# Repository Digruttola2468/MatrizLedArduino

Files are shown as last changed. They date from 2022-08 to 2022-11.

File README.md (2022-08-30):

# Matriz Led Arduino
En este proyecto por parte de la escuela Gomara, queremos mostrar la hora y temperatura por medio de display 7segmentos y de Matrices de Led.

Para obtener los datos de temperatura y fecha necesitamos de los siguientes modulos:
-	DHT11 o DHT22 --- Sensor de temperatura y humedad
-	RTC3231 --- Modulo de reloj y fecha con la funcionalidad de Alarma

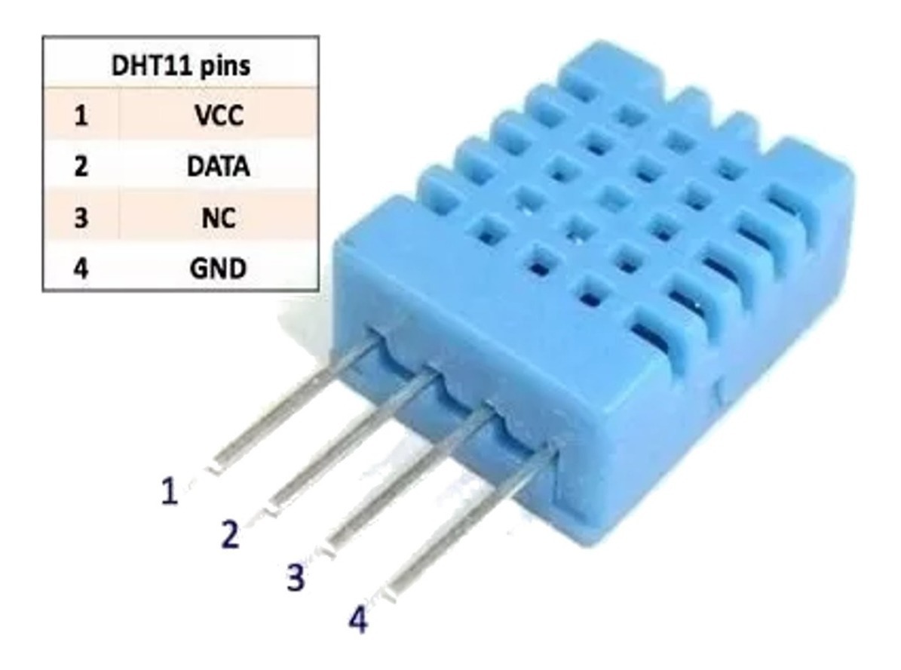
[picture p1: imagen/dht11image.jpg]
DHT11
 
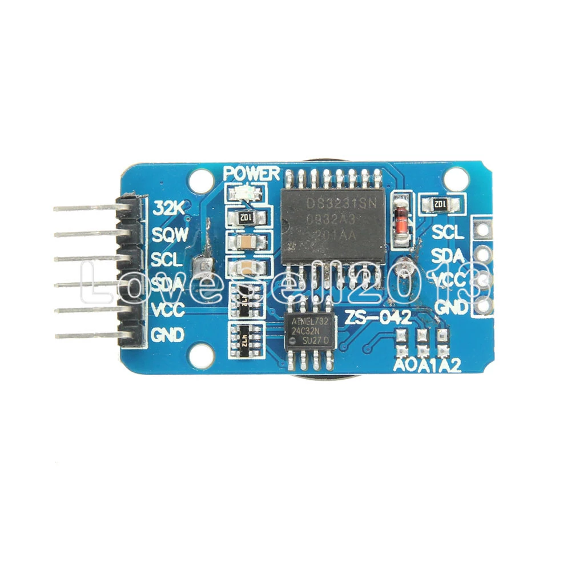
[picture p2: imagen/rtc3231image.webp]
RTC3231


En el sensor DHT11 usaremos los pines excepto NC, conectando:
- VCC --- 5v   
- GND --- GND   
- DATA --- PIN 4 

En el modulo RTC3231 usaremos los pines:
- VCC --- 5v     
- GND --- GND    
- SDA, SCL --- Pines Digitales arduino

## Incluir librerias modulos
Para obtener los datos de los modulos necesitamos de librerias. Para descargar librerias en arduino necesitamos ir a _Programa/Incluir Libreria/Administrar Bibliotecas_

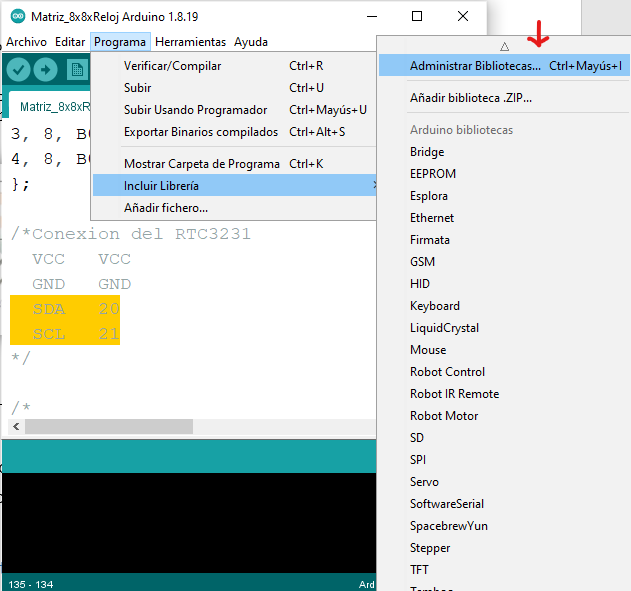
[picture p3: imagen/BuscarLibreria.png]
Incluir Libreria


Luego buscamos DHT11 y seleccionamos la libreria con autor Adafuit (podes descargar cualquier version).
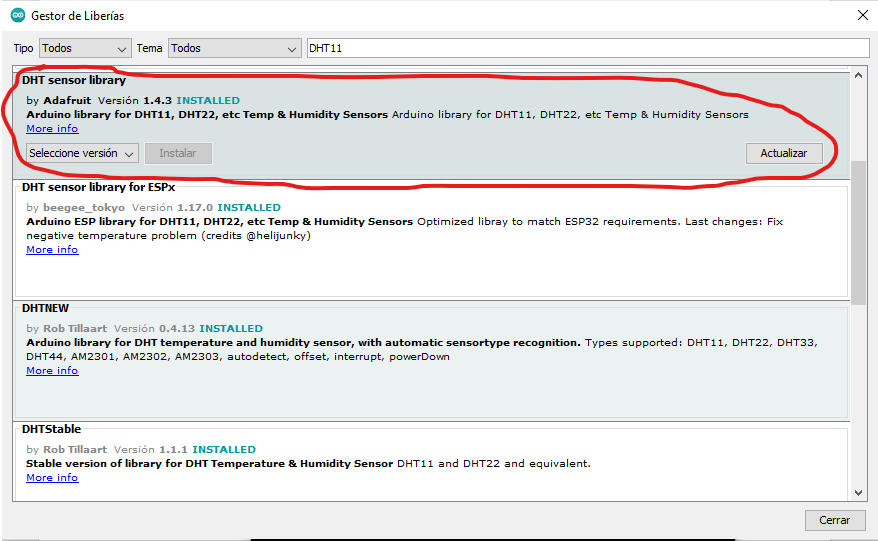
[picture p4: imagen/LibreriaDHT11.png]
Libreria DHT11


Y para el Modulo RTC3231
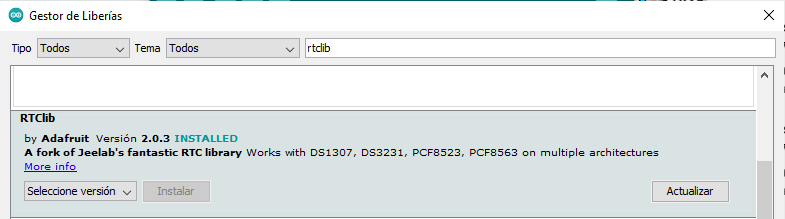
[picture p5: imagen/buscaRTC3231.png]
Libreria RTC3231


## Mostrar los datos
Listo ya tenemos las librerías instaladas y el programa funcionando obteniendo los datos de temperatura y hora, ahora falta mostrar los datos para que el usuario lo pueda visualizar.

Para mostrar los datos usaremos Display 7 segmentos para mostrar la hora y matrices de led para mostrar la temperatura, humedad y la fecha.

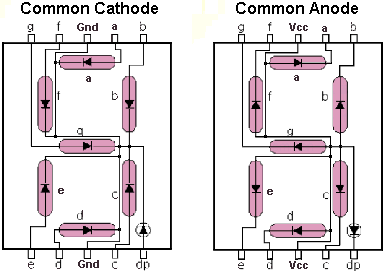
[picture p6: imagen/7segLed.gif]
Display 7 segmentos


En los Display de 7 segmentos podemos tener dos tipos, anodo comun o catodo comun, modificando su cableado como muestra en la imagen. Tambien es necesario agregarle resistencias antes de conectar al Arduino ya que los LED del display de 7 segmentos soportan 2v (si son grandes los display funcionan con 8v o 9v) y el arduino entrega 5v como salida. Hay que tener en cuenta el [multiplexado](#multiplexado) para mostrar la hora sin que muestre numeros repetidos.

Para la matriz de led es mucho mas sencillo ya que la [libreria](#libreria-matriz-de-led) junto con el programa lo hace todo. En los pines rojos son los pines de salida para conectar otras matrices para que haga la funcion de cascada, mostrando un texto completo por ejemplo.

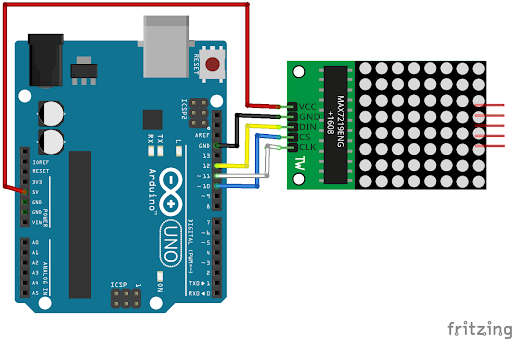
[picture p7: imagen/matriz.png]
Matriz Led

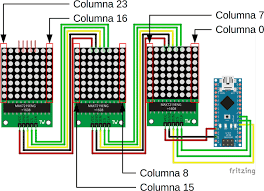
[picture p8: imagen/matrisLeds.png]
Cascada Matriz Leds


Los pines **DIN CS CLK** los conectamos en los pines digitales del arduino, la alimentacion del mismo necesita de 5v para funcionar.

## Cerebro de nuestro programa
Ya con estos conceptos necesitamos saber que arduino utilizar para el cerebro de toda nuestra logica, existen muchos tipos de arduino, nosotros usaremos un **Arduino MEGA**.

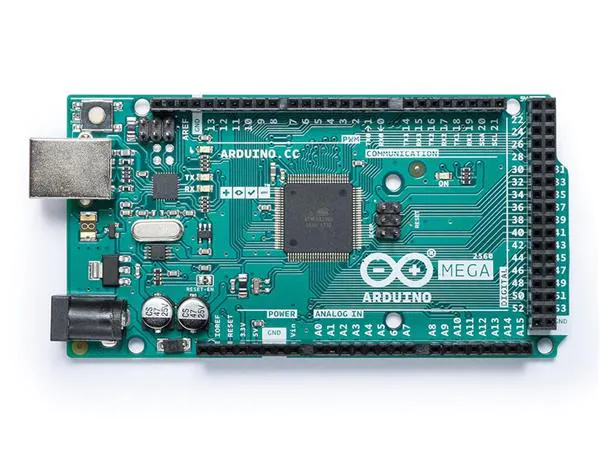
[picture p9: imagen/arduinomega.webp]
Arduino Mega


Para realizar la logica de nuestro programa usaremos el IDE (Integrated development environment) oficial de arduino lo podemos descargar por la pagina oficial o por Microsoft Store (si es que tienes Windows 10).
[Download Arduino](https://www.arduino.cc/en/software)

## Multiplexado
Si queremos mostrar que son las 16 30 tenemos en cada display un numero distinto, para esto necesitamos prender un solo display, mostrar el numero  1 y luego apagar y prender el siguiente display mostrando un 6 y asi sucesivamente, el tiempo entre display tiene que ser un tiempo muy corto aproximadamente 25 nanosegundos cosa que no sea visible por el ojo humano.

## Libreria Matriz de Led
Para la matriz de led necesitamos incluir la libreria por fuera

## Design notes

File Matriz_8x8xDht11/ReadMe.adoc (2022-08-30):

:Author: ProfeGarcia
:Email: el_profe_garcia@hotmail.com
:Date: 07/06/2018
:Revision: version#
:License: Public Domain

= Project: {Project}

Describe your project

== Step 1: Installation
Please describe the steps to install this project.

For example:

1. Open this file
2. Edit as you like
3. Release to the World!

== Step 2: Assemble the circuit

Assemble the circuit following the diagram layout.png attached to the sketch

== Step 3: Load the code

Upload the code contained in this sketch on to your board

=== Folder structure

....
 sketch123                => Arduino sketch folder
  ├── sketch123.ino       => main Arduino file
  ├── schematics.png      => (optional) an image of the required schematics
  ├── layout.png          => (optional) an image of the layout
  └── ReadMe.adoc         => this file
....

=== License
This project is released under a {License} License.

=== Contributing
To contribute to this project please contact ProfeGarcia <el_profe_garcia@hotmail.com>

=== BOM
Add the bill of the materials you need for this project.

|===
| ID | Part name      | Part number | Quantity
| R1 | 10k Resistor   | 1234-abcd   | 10       
| L1 | Red LED        | 2345-asdf   | 5        
| A1 | Arduino Zero   | ABX00066    | 1        
|===

=== Help
This document is written in the _AsciiDoc_ format, a markup language to describe documents. 
If you need help you can search the http://www.methods.co.nz/asciidoc[AsciiDoc homepage]
or consult the http://powerman.name/doc/asciidoc[AsciiDoc cheatsheet]

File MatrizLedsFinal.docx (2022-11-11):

# Introducción

Grupo: Iván Di Gruttola y Bruno Ruiz Díaz

Año: 6to Curso: A

Proyecto: Matriz de Leds

Descripción: Este proyecto fue elegido para mostrar la Hora y Temperatura, ante una necesidad de la escuela de tener un reloj digital donde muestra más allá de la hora, sino también la fecha, temperatura y humedad del lugar.

Objetivos: Visualizar Hora con Display 7 segmentos y la Temperatura, Humedad y Fecha actual con Matriz de Led.

Ciclo Lectivo: 2022

# Alternativa de Solución

Los objetivos de este proyecto es mostrar Hora, Temperatura, Humedad y la Fecha actual. Pero ante esto surge la duda de ¿Cómo se puede mostrar dichos valores? Bueno, acá existen varias opciones como:

- Display 7 segmentos
- Matriz de Leds
- LCD
- Oled

Como nuevo objetivo también es mostrar a mediana distancia para mostrar en un salón o en un lugar en el recreo, asique la alternativa de solución será utilizar un Display 7segmentos de 19.0mm x 12.60mm para luego usar uno grande de 69.70mm a 47.80mm y las Matriz de Leds de 32mm x 32mm apiladas de forma horizontal mostrando un texto largo. Después en cada módulo mostramos sus alternativas de solución ya que existen distintos módulos para resolver el mismo problema.

# DISEÑO

## Módulos

#### DHT11

Para mostrar los valores de temperatura y humedad se necesitarían de módulos ya que por sí solo no podemos obtener esos valores con el arduino. El DHT11 es una excelente opción ya que existen también otros como el DHT22 que tiene un rango de temperatura mayor (-40°C a 80°C) también posee una alta precisión de temperatura (+- 0.5°C), pero ya con el rango que tiene el DHT11 (0°C a 50°C) bastaría para usos básicos.

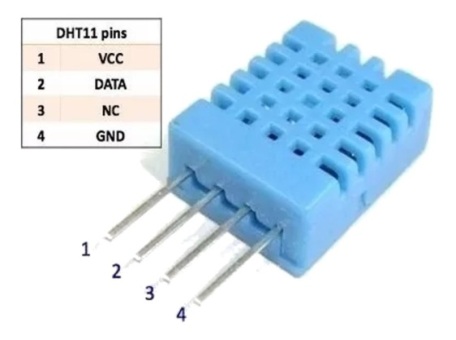
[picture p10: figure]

#### RTC3231

Con programación y con un poco de hardware se puede obtener la hora actual pero provocaría que cada vez que se apague el arduino se reinicie la hora, ante este problema es mejor usar módulos especializados en esto y obtener resultados precisos. El módulo RTC3231 nos obtiene la Hora y Fecha, permitiendo también agregar alarmas.

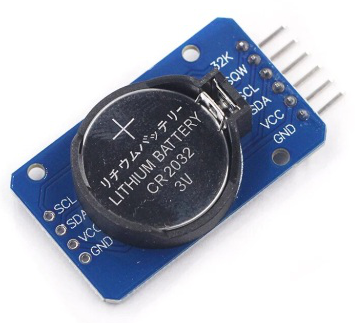
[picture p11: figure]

#### HC-05 Bluetooth

Algo adicional que se puede agregar al proyecto es usar el módulo HC-05 Bluetooth donde desde un celular escribís un texto cualquiera y se envía al arduino para mostrar en las matrices de led dicho texto.

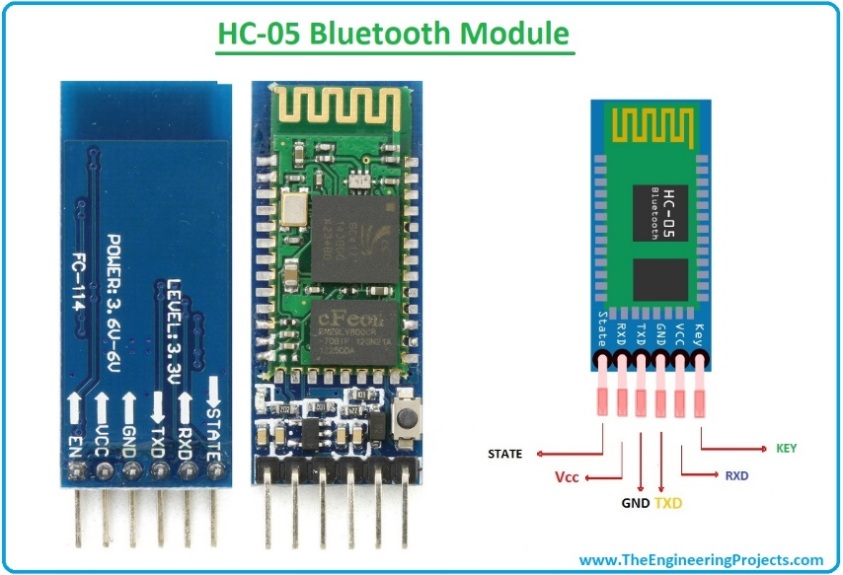
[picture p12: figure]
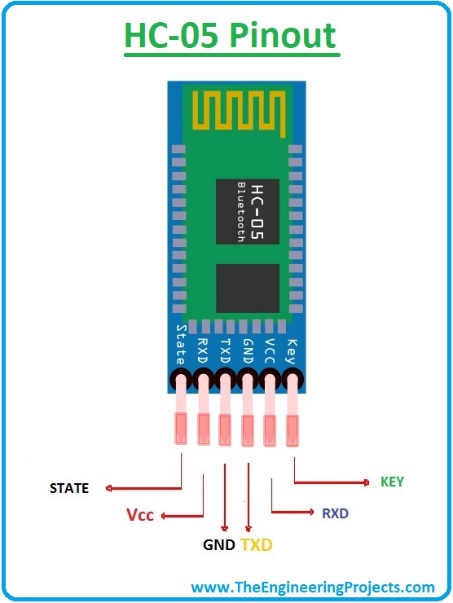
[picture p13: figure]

## Cerebro de nuestro programa

Para obtener los datos de los módulos requerimos de arduino que será el cerebro de toda nuestra lógica, existen muchos tipos de arduino. La siguiente imagen es un arduino mega:

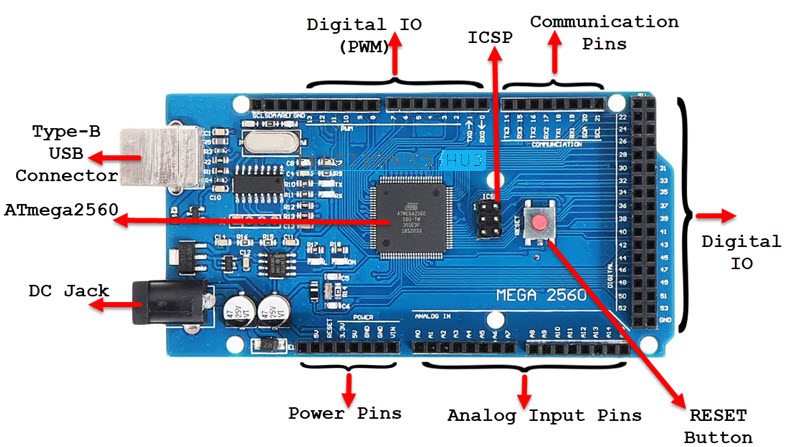
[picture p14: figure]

Para realizar la lógica del programa se necesitara de un IDE (Integrated development environment) oficial de arduino, lo podemos descargar gratis por la página oficial o por Microsoft Store (si es que tienes Windows 10).

## Porque arduino mega y no un arduino Uno??

Los arduino mega se caracterizan por ser mejores que Arduino Uno, ya que poseen:

+ Pines digitales + Pines Analogicos +Puertos de Comunicacion + Memoria

Para los display 7seg, para el multiplexado y para las matriz de leds, se necesitaran en total 14 pines digitales, pero el arduino uno soporta hasta 11 pines digitales, para eso usamos un Arduino Mega.

## Gestión Tiempo

| | Junio | | | | Julio | | | | Agosto | | | | Septiembre | | | | Octubre | | | | Noviembre
Actividades | | 1 | 2 | 3 | 4 | 1 | 2 | 3 | 4 | 1 | 2 | 3 | 4 | 1 | 2 | 3 | 4 | 1 | 2 | 3 | 4 | 1 | 2 | 3 | 4
Programa
PCB
Informe del Proyecto
SolidWork

## Diagrama Display

Para mostrar la hora se necesitara de 4 Display de 7 segmentos donde se usara el método de Multiplexado para mostrar distintos números en cada display, por ejemplo 16:30.


En los Display de 7 segmentos existen dos tipos, cátodo común o ánodo común, modificando su cableado como muestra en la imagen. También es necesario agregarle resistencias antes de conectar al Arduino ya que los LED del display de 7 segmentos necesitan 2v (si son grandes los display funcionan con 8v o 9v) y el arduino entrega 5v como salida. Hay que tener en cuenta también el multiplexado para mostrar la hora sin que muestre números repetidos.

## Multiplexado

Para mostrar que son las 16 30 tenemos en cada display un numero distinto, para esto prender un solo display, mostrar el número 1 y luego apagar y prender el siguiente display mostrando un 6 y así sucesivamente, el tiempo entre display tiene que ser un tiempo muy corto aproximadamente 25 nanosegundos cosa que no sea visible por el ojo humano. Esta secuencia de prender uno de los demás lo realiza gracias a los transistores.

### Conexión del multiplexado

El transistor NPN vendría bien para este proyecto, usando un BC546 donde posee un hfe de 110 – 450, este rango es el que permite estar en corto y en saturación al transistor, funcionando como llave. Donde la salida del arduino es de 5v, necesitara de una resistencia para disminuir la corriente y llegando al rango del hfe para que el transistor sature y conecte el display 7 segmentos a masa (negativo). En nuestro caso nosotros colocamos una Resistencia de 2k2ohm en la base del transistor.

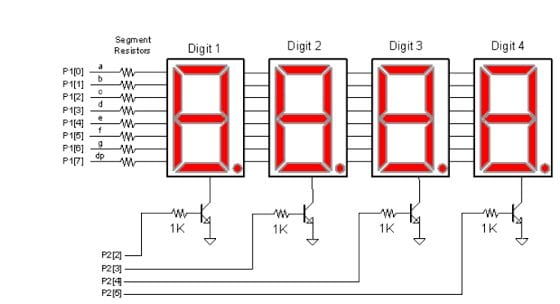
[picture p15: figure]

## Diagrama Temperatura y Fecha

Para mostrar la temperatura, humedad y fecha en la matriz de led es mucho más sencillo ya que la librería junto con el programa lo hace todo, no es necesario usar el método de multiplexado. En los pines rojos de la imagen son los pines de salida para conectar otras matrices para que haga la función de cascada, mostrando un texto completo.

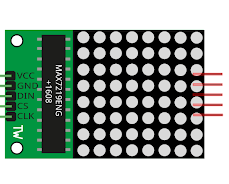
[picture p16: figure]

Los pines DIN CS CLK se conectan en los pines digitales del arduino mega y la alimentación del mismo necesita de 5v para funcionar.

# Librería para los sensores

Las librerías son código realizado por otros programadores para obtener los datos de los módulos. Para descargar librerías en arduino ir a Programa/Incluir Librería/Administrar Bibliotecas.

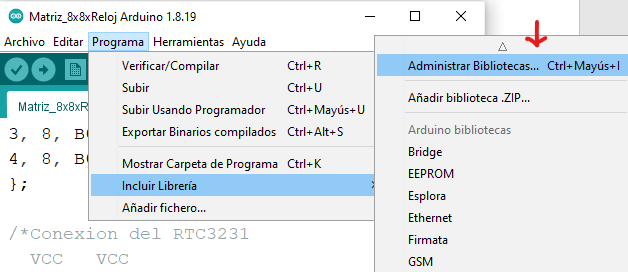
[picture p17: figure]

Luego buscar DHT11 y seleccionar la librería con autor Adafruit (podes descargar cualquier versión).

Para el módulo RTC3231

# Diagrama General Completo Del Conexionado

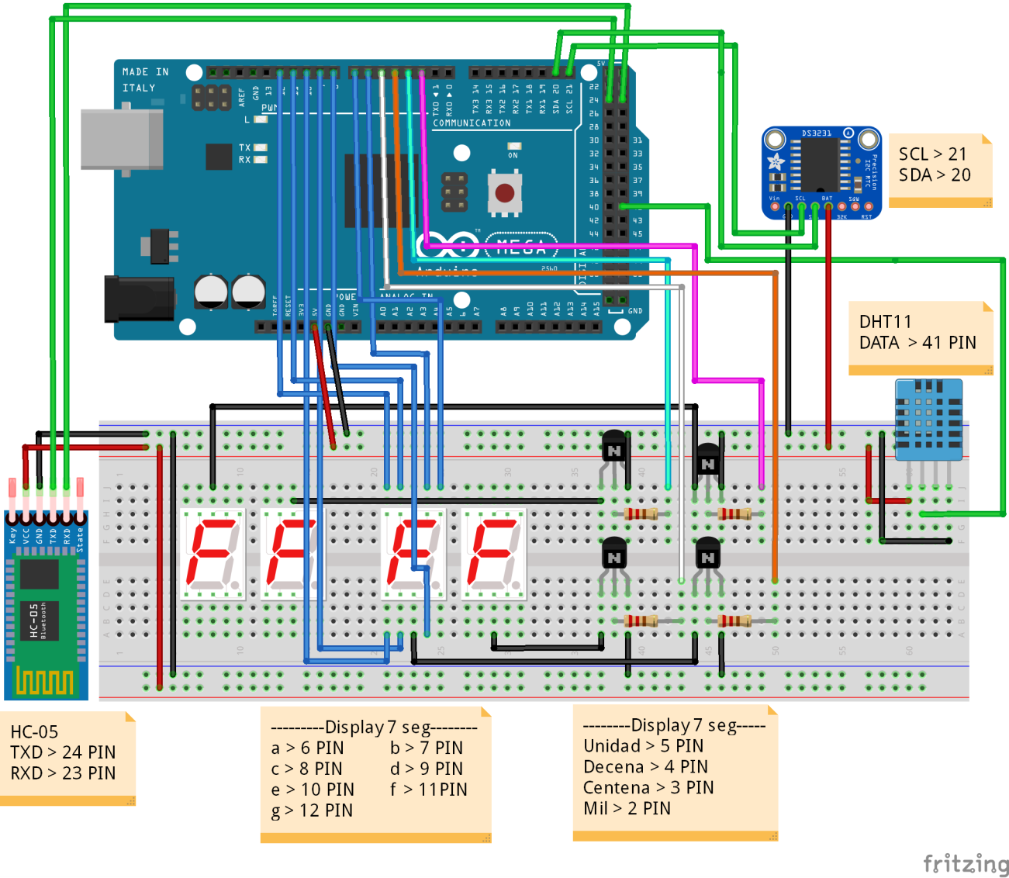
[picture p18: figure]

# PCB Wizard

Se deberá utilizar un software que pueda realizar el diseño en PCB (Printed circuit board que se traduce Placa de circuito impreso) para luego montarlo en una caja sin necesidad de utilizar una protoboard. El siguiente diseño es para conectar las matrices de led entre sí, simplificando el uso de cables cables.

En este diseño conectamos de forma vertical las matrices de led que en el diseño pertenece la parte de abajo (Matriz de Led), conectando la parte inferior de la matriz y la parte superior colocamos unos cables hembra – macho para luego conectarlo en la placa, en el diseño seria la parte superior (Cables).

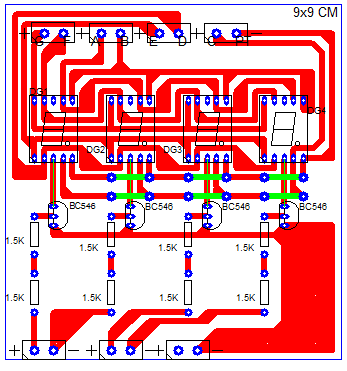
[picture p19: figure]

La imagen representa al diseño de la placa en PCB para la conexión de los Display 7seg de tamaño 19.0mm x 12.60mm donde ya está el método de multiplexado conectado. Donde las borneras de la parte superior se conectan los Display 7Seg entre si y la parte inferior los transistores para prender dicho Display.

# Lista Software del Proyecto

Los siguientes software se usaron para las siguientes tareas

Arduino: Código del programa

Microsoft Word: Informe del proyecto

Fritzing: Diagrama completo de las conexiones del proyecto

PCB Wizard: Diseño en PCB para Matriz de led

Microsoft Excel: Diagrama de Gantt

# Imagen Del Proyecto

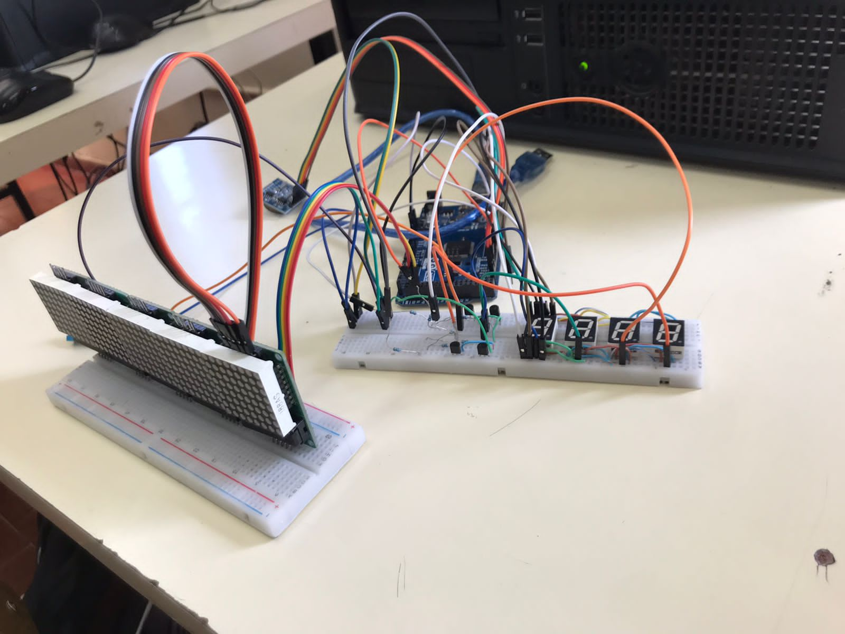
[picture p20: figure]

# Biografía

Módulo DHT11: https://www.youtube.com/watch?v=2tdsg_K-oQQ

Módulo RTC3231: https://www.youtube.com/watch?v=ZOMXEYuQwwY

Modulo HC-05: https://www.youtube.com/watch?v=5SmKOUHhmWk

https://www.youtube.com/watch?v=kSl8SUb5L9A

Download Arduino: https://www.arduino.cc/en/software

Matriz de Led https://www.youtube.com/watch?v=_QNUIiuW2N0&t=1788s&ab_channel=BitwiseAr

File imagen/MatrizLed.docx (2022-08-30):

# Matriz de Leds

En este proyecto nos basamos en mostrar Hora y Temperatura usando sus respectivos módulos.

- DHT11 o DHT22 --- Sensor de temperatura y humedad (imagen 1)
- RTC3231 --- Modulo de reloj con la funcionalidad de Alarma (imagen 2)

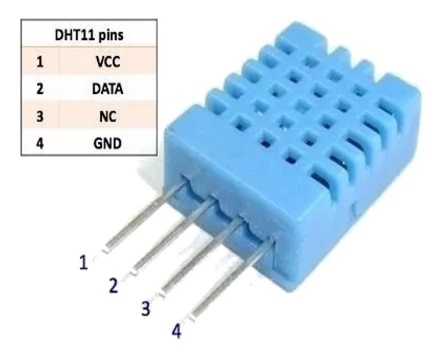
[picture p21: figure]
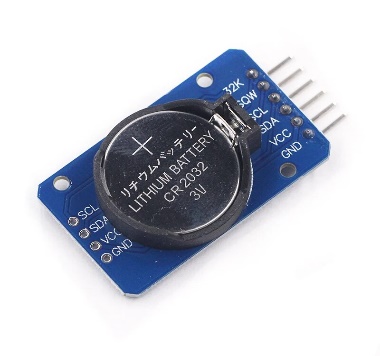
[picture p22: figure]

Imagen 1 Imagen 2

En el sensor DHT11 usaremos los pines excepto NC, conectando:

VCC --- 5v GND --- GND DATA --- PIN 4

En el módulo RTC3231 usaremos los pines:

VCC --- 5v GND --- GND SDA --- 20 SCL --- 21

# Librería para los sensores

Para obtener los datos de los módulos necesitamos de librerías. Para descargar librerías en arduino necesitamos ir a Programa/Incluir Librería/Administrar Bibliotecas


Luego buscamos DHT11 y seleccionamos la librería con autor Adafuit (podes descargar cualquier versión).

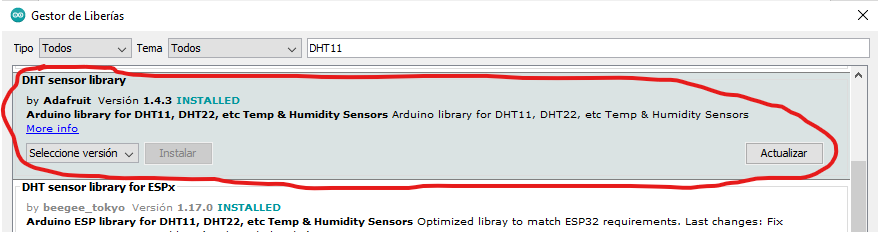
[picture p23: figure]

Para el modulo RTC3231


# Mostrar los datos

Listo ya tenemos las librerías instaladas y el programa funcionando obteniendo los datos de temperatura y hora, ahora falta mostrar los datos para que el usuario lo pueda visualizar.

Para mostrar los datos usaremos Display 7 segmentos para mostrar la hora y matrices de led para mostrar la temperatura, humedad y la fecha.


En los Display de 7 segmentos podemos tener dos tipos, ánodo común o cátodo común, modificando su cableado como muestra en la imagen. También es necesario agregarle resistencias antes de conectar al Arduino ya que los LED del display de 7 segmentos necesitan 2v (si son grandes los display funcionan con 8v o 9v) y el arduino entrega 5v como salida. Hay que tener en cuenta el multiplexado para mostrar la hora sin que muestre números repetidos.

Para la matriz de led es mucho más sencillo ya que la librería junto con el programa lo hace todo. En los pines rojos son los pines de salida para conectar otras matrices para que haga la función de cascada, mostrando un texto completo, por ejemplo.


Los pines DIN CS CLK los conectamos en los pines digitales del arduino, la alimentación del mismo necesita de 5v para funcionar.

# Cerebro de nuestro programa

Ya con estos conceptos necesitamos saber que arduino utilizar para el cerebro de toda nuestra lógica, existen muchos tipos de arduino, nosotros usaremos un Arduino MEGA

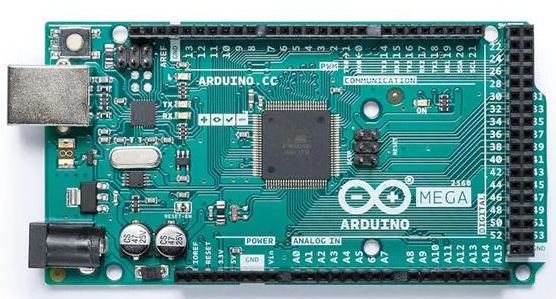
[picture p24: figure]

Para realizar la lógica de nuestro programa usaremos el IDE (Integrated development environment) oficial de arduino lo podemos descargar por la página oficial o por Microsoft Store (si es que tienes Windows 10) https://www.arduino.cc/en/software

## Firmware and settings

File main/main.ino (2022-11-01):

//----------------Librerias--------------------
//MaxMatriz
#include <MaxMatrix.h>

//Sensor Temperatura y Humedad
#include <DHT.h>
#include <DHT_U.h>

//RTC3231
#include<Wire.h>
#include<RTClib.h>

//Caracteres para displayar la matriz de led
PROGMEM unsigned char const CH[] = {
3, 8, B00000000, B00000000, B00000000, B00000000, B00000000, // space
1, 8, B01011111, B00000000, B00000000, B00000000, B00000000, // !
3, 8, B00000011, B00000000, B00000011, B00000000, B00000000, // "
5, 8, B00010100, B00111110, B00010100, B00111110, B00010100, // #
4, 8, B00100100, B01101010, B00101011, B00010010, B00000000, // $
5, 8, B01100011, B00010011, B00001000, B01100100, B01100011, // %
5, 8, B00110110, B01001001, B01010110, B00100000, B01010000, // &
1, 8, B00000011, B00000000, B00000000, B00000000, B00000000, // '
3, 8, B00011100, B00100010, B01000001, B00000000, B00000000, // (
3, 8, B01000001, B00100010, B00011100, B00000000, B00000000, // )
5, 8, B00101000, B00011000, B00001110, B00011000, B00101000, // *
5, 8, B00001000, B00001000, B00111110, B00001000, B00001000, // +
2, 8, B10110000, B01110000, B00000000, B00000000, B00000000, // ,
4, 8, B00001000, B00001000, B00001000, B00001000, B00000000, // -
2, 8, B01100000, B01100000, B00000000, B00000000, B00000000, // .
4, 8, B01100000, B00011000, B00000110, B00000001, B00000000, // /
4, 8, B00111110, B01000001, B01000001, B00111110, B00000000, // 0
3, 8, B01000010, B01111111, B01000000, B00000000, B00000000, // 1
4, 8, B01100010, B01010001, B01001001, B01000110, B00000000, // 2
4, 8, B00100010, B01000001, B01001001, B00110110, B00000000, // 3
4, 8, B00011000, B00010100, B00010010, B01111111, B00000000, // 4
4, 8, B00100111, B01000101, B01000101, B00111001, B00000000, // 5
4, 8, B00111110, B01001001, B01001001, B00110000, B00000000, // 6
4, 8, B01100001, B00010001, B00001001, B00000111, B00000000, // 7
4, 8, B00110110, B01001001, B01001001, B00110110, B00000000, // 8
4, 8, B00000110, B01001001, B01001001, B00111110, B00000000, // 9
2, 8, B01010000, B00000000, B00000000, B00000000, B00000000, // :
2, 8, B10000000, B01010000, B00000000, B00000000, B00000000, // ;
3, 8, B00010000, B00101000, B01000100, B00000000, B00000000, // <
3, 8, B00010100, B00010100, B00010100, B00000000, B00000000, // =
3, 8, B01000100, B00101000, B00010000, B00000000, B00000000, // >
4, 8, B00000010, B01011001, B00001001, B00000110, B00000000, // ?
5, 8, B00111110, B01001001, B01010101, B01011101, B00001110, // @
4, 8, B01111110, B00010001, B00010001, B01111110, B00000000, // A
4, 8, B01111111, B01001001, B01001001, B00110110, B00000000, // B
4, 8, B00111110, B01000001, B01000001, B00100010, B00000000, // C
4, 8, B01111111, B01000001, B01000001, B00111110, B00000000, // D
4, 8, B01111111, B01001001, B01001001, B01000001, B00000000, // E
4, 8, B01111111, B00001001, B00001001, B00000001, B00000000, // F
4, 8, B00111110, B01000001, B01001001, B01111010, B00000000, // G
4, 8, B01111111, B00001000, B00001000, B01111111, B00000000, // H
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
4, 8, B00000001, B00000110, B00011000, B01100000, B00000000, // \ backslash
2, 8, B01000001, B01111111, B00000000, B00000000, B00000000, // ]
3, 8, B00000010, B00000001, B00000010, B00000000, B00000000, // hat
4, 8, B01000000, B01000000, B01000000, B01000000, B00000000, // _
2, 8, B00000001, B00000010, B00000000, B00000000, B00000000, // `
4, 8, B00100000, B01010100, B01010100, B01111000, B00000000, // a
4, 8, B01111111, B01000100, B01000100, B00111000, B00000000, // b
4, 8, B00111000, B01000100, B01000100, B00101000, B00000000, // c
4, 8, B00111000, B01000100, B01000100, B01111111, B00000000, // d
4, 8, B00111000, B01010100, B01010100, B00011000, B00000000, // e
3, 8, B00000100, B01111110, B00000101, B00000000, B00000000, // f
4, 8, B10011000, B10100100, B10100100, B01111000, B00000000, // g
4, 8, B01111111, B00000100, B00000100, B01111000, B00000000, // h
3, 8, B01000100, B01111101, B01000000, B00000000, B00000000, // i
4, 8, B01000000, B10000000, B10000100, B01111101, B00000000, // j
4, 8, B01111111, B00010000, B00101000, B01000100, B00000000, // k
3, 8, B01000001, B01111111, B01000000, B00000000, B00000000, // l
5, 8, B01111100, B00000100, B01111100, B00000100, B01111000, // m
4, 8, B01111100, B00000100, B00000100, B01111000, B00000000, // n
4, 8, B00111000, B01000100, B01000100, B00111000, B00000000, // o
4, 8, B11111100, B00100100, B00100100, B00011000, B00000000, // p
4, 8, B00011000, B00100100, B00100100, B11111100, B00000000, // q
4, 8, B01111100, B00001000, B00000100, B00000100, B00000000, // r
4, 8, B01001000, B01010100, B01010100, B00100100, B00000000, // s
3, 8, B00000100, B00111111, B01000100, B00000000, B00000000, // t
4, 8, B00111100, B01000000, B01000000, B01111100, B00000000, // u
5, 8, B00011100, B00100000, B01000000, B00100000, B00011100, // v
5, 8, B00111100, B01000000, B00111100, B01000000, B00111100, // w
5, 8, B01000100, B00101000, B00010000, B00101000, B01000100, // x
4, 8, B10011100, B10100000, B10100000, B01111100, B00000000, // y
3, 8, B01100100, B01010100, B01001100, B00000000, B00000000, // z
3, 8, B00001000, B00110110, B01000001, B00000000, B00000000, // {
1, 8, B01111111, B00000000, B00000000, B00000000, B00000000, // |
3, 8, B01000001, B00110110, B00001000, B00000000, B00000000, // }
4, 8, B00001000, B00000100, B00001000, B00000100, B00000000, // ~
};

/*-----------------------Conexion de modulos-------------------------- 
Conexiones del Arduino al Modulo MAX7219 Matriz de Leds:
ARDUINIO    MAX7219
 35         CLK
 34          CS
 33          DIN
 GND         GND
 5V          VCC
 
Conexion  de la cascada de MAX7219(1) al MAX7219(2)
MAX7219(1)   MAX7219(2)  
  CLK          CLK
  CS           CS
  DOUT         DIN
  GND          GND
  VCC          VCC

Conexion con DHT11
   Vista de frente Izquierda a derecha
   1 -> VCC
   2 -> DATA -> PIN Digital
   3 -> NC (No se conecta)
   4 -> GND

Conection RTC3231
    SDA --> 20 SDA 
    SCL --> 21 SCL 

Conexion Display 7 segmentos
  Display Mil     -> PIN Digital
  Display Centena -> PIN Digital
  Display Decena  -> PIN Digital
  Display Unidad  -> PIN Digital

DIS_MIL 5
DIS_CEN 3
DIS_DEC 2
DIS_UNI 4

Conexion Pines 7 segmentos -> PINES DIGITALES
  6,7,8,9,10,11,12
  a,b,c,d, e, f, g
*/


//-----------------------------PIN------------------------------------

//Pines Display 7 segmentos
const int pins[7] = {6,7,8,9,10,11,12};
//                   a,b,c,d,e ,f ,g 

//Pines Matriz de Leds
#define DATA  51    // DIN pin del modulo MAX7219
#define LOAD  52    // CS pin del modulo MAX7219
#define CLOCK 53   // CLK pin del modulo MAX7219

//Pin DHT11 Sensor Temperatura y Humedad
#define DHTPIN 41  // PIN DHT11


//Mostrar numeros en el Display 7seg
const byte numbersDisplayAnode[10] = {
//0b0gfedcba
  0b00111111, //0 
  0b00000110, //1
  0b01011011, //2
  0b01001111, //3
  0b01100110, //4
  0b01101101, //5
  0b01111101, //6
  0b00000111, //7
  0b11111111, //8
  0b11101111  //9
};

//-----------------------------Modulos------------------------------------
//Modulo 3231
RTC_DS3231 rtc;

//Modulo DHT11 sensor Temperatura y Humedad
DHT dht(DHTPIN, DHT11);                   // PINMODEL,DHTMODEL 

//Modulo Matriz de Leds
MaxMatrix m(DATA, LOAD, CLOCK, maxInUse); // Define el modulo



//-----------------------------Variables------------------------------------

//Variables para el reloj
int horaAlta = 0;
int horaBaja = 0;
int minutoAlto = 0;
int minutoBajo = 0;

//Variable MaxMatrix
int maxInUse = 2;    // Cambie este valor dependiendo del numero de matrices que use
byte buffer[2];
char mensaje1[] =  ""; // Escriba el mensaje a desplegar 

//Variable DHT
float temp = 25;
float humedad = 5;


void setup(){
  Serial.begin(9600);       // Inicializa el puerto serial
 
  m.init();                 // Inicializa el modulo Matriz de led
  m.setIntensity(5);        // Intencidad de los puntos de la matriz, entre 1-5
  
  pinMode(DHTPIN,OUTPUT);   // Definimos como salida el pin DHT

  //Verificamos si se conecto con el Modulo RTC3231
  if( !rtc.begin() ) {
    Serial.println("Modulo RTC no encontrado");
    while(1); //Bucle infinito
  }
  
  rtc.adjust(DateTime(__DATE__,__TIME__));

  //Definimos como salida a los pines Display 7seg
  for(int i=0; i<7 ; i++){
    pinMode(pins[i], OUTPUT);
  }
  
  //Transistores para multiplexado, definimos como salida
  pinMode(DIS_MIL,OUTPUT);
  pinMode(DIS_CEN,OUTPUT);
  pinMode(DIS_DEC,OUTPUT);
  pinMode(DIS_UNI,OUTPUT);
}

void loop(){
  byte c;
  
  // Lee el mensaje que llega por el puerto serial
  while (Serial.available() > 0){
    byte c = Serial.read();         //Obtiene de cada byte
    Serial.println(c,DEC);
    printCharWithShift(c, 100);
  }

  //Obtenemos los valores del sensor de temperatura 
  temp    = dht.readTemperature(); //Lee Temperatura DHT11
  humedad = dht.readHumidity();    //Lee Humedad DHT11

  //Creamos una cadena de caracteres para la frase de temperatura y humedad
  String stringMensaje;
  stringMensaje += "Temperatura: ";
  stringMensaje += temp;
  stringMensaje += "  Humedad: ";
  stringMensaje += humedad;

  //Obtenemos la cantidad total de los caracteres del string
  int mensajeLength = stringMensaje.length() + 1;

  //Pasamos de String a char[]
  char charMensaje[mensajeLength];
  stringMensaje.toCharArray(charMensaje,50);
  
  //Mostrar en la Matriz de Led
  printStringWithShift(charMensaje, 100);       // El ultimo termino se usa para la velocidad del mensaje  

  //Obtenemos la fecha y hora
  DateTime fecha = rtc.now();

  //Obtenemos los valores del modulo RTC3231
  int horas  = fecha.hour();                  
  int minutos = fecha.minute();               

  //Mostrar hora minutos en los display 7 segmentos
  mostrarHoraDisplay7seg(horas,minutos);
}

//---------------------Funciones-----------------------------------------------------------------
void printCharWithShift(char c, int shift_speed){    // Imprime caracteres
  //32 --> ALT+32 --> space
  if (c < 32) 
    return;
  
  c -= 32; 
  memcpy_P(buffer, CH + 7*c, 7);
  m.writeSprite(maxInUse*8, 0, buffer);
  m.setColumn(maxInUse*8 + buffer[0], 0);
  
  for (int i=0; i<buffer[0]+1; i++) {
    delay(shift_speed);
    m.shiftLeft(false, false);
  }
}

void printStringWithShift(char* s, int shift_speed){        // Imprime cadena de caracteres
  while (*s != 0){
    printCharWithShift(*s, shift_speed);
    s++;
  }
}

void printString(char* s)                            // Imprime cadena
{
  int col = 0;
  while (*s != 0){
    if (*s < 32) 
      continue;
    
    char c = *s - 32;
    memcpy_P(buffer, CH + 7*c, 7);
    m.writeSprite(col, 0, buffer);
    m.setColumn(col + buffer[0], 0);
    col += buffer[0] + 1;
    s++;
  }
}

void mostrarHoraDisplay7seg(int hora,int minutos){
  
  horaAlta = hora / 10;                      //20 / 10 = 2
  horaBaja = hora - (horaAlta * 10);         //20 - ( 2 * 10 ) = 0
  
  minutoAlto = minutos / 10;                  //47 / 10 = 4.7
  minutoBajo = minutos - (minutoAlto * 10) ; //47 - (4 * 10) = 7

  Serial.print(horaAlta);
  Serial.print(horaBaja);
  
  Serial.print(":");

  Serial.print(minutoAlto);
  Serial.println(minutoBajo);
  
  int tiempo = 2;
  
  //Mostrar Hora
  digitalWrite(DIS_UNI, HIGH);
  delay(tiempo);
  lightSegments(minutoBajo);
  digitalWrite(DIS_UNI, LOW);
  delay(tiempo);

  digitalWrite(DIS_DEC, HIGH);
  delay(tiempo);
  lightSegments(minutoAlto);
  digitalWrite(DIS_DEC, LOW);
  delay(tiempo);

  digitalWrite(DIS_CEN, HIGH);
  delay(tiempo);
  lightSegments(horaBaja);
  digitalWrite(DIS_CEN, LOW);
  delay(tiempo);

  digitalWrite(DIS_MIL, HIGH);
  delay(tiempo);
  lightSegments(horaAlta);
  digitalWrite(DIS_MIL,LOW);
  delay(tiempo);
}

void lightSegments(int number) {
  byte numberBit = numbersDisplayAnode[number];

  //Recorremos dentro de los 7 pines
  for(int i=0 ; i<7 ; i++){
    int bit = bitRead(numberBit, i); //Obtenemos ese bite a int
    digitalWrite(pins[i], bit);      //Enciamos
  }  
}

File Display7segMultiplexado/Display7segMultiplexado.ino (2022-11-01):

// 2,3,4,5 PIN Transistores
// 6,7,8,9,10,11,12 PIN Display 7seg
// a,b,c,d,e,f,g

const int pins[7] = {6,7,8,9,10,11,12};
//                   a , b, c, d, e, f, g 

#define DIS_MIL 4   //PIN 2
#define DIS_CEN 3   //PIN 3
#define DIS_DEC 2   //PIN 4
#define DIS_UNI 5   //PIN 5

//0b0gfedcba
const byte numbersDisplayAnode[10] = {
  0b00111111, //0 
  0b00000110, //1
  0b01011011, //2
  0b01001111, //3
  0b01100110, //4
  0b01101101, //5
  0b01111101, //6
  0b00000111, //7
  0b11111111, //8
  0b11101111  //9
};

int unidad = 0;
int decena = 0;
int centena = 0;
int mil = 0;

void setup(){
  for(int i=0; i<7 ; i++){
    pinMode(pins[i], OUTPUT);
  }
  
  //Transistores
  pinMode(DIS_MIL,OUTPUT);
  pinMode(DIS_CEN,OUTPUT);
  pinMode(DIS_DEC,OUTPUT);
  pinMode(DIS_UNI,OUTPUT);
}

void loop(){
  
  if(unidad == 10 ){
    unidad = 0;
    decena++;
  }
  if(decena == 10) {
    decena = 0;
    unidad = 0;
    centena++;
  }
  if(centena == 10){
    unidad = 0;
    decena = 0;
    centena = 0;
    mil++;
  }
  if(mil == 10){
    unidad = 0;
    decena = 0;
    centena = 0;
    mil = 0;
  }

  int tiempo = 100;
  
  //Mostrar Hora
  digitalWrite(DIS_UNI, HIGH);
  delay(tiempo);
  lightSegments(unidad);
  digitalWrite(DIS_UNI, LOW);
  delay(tiempo);

  digitalWrite(DIS_DEC, HIGH);
  delay(tiempo);
  lightSegments(decena);
  digitalWrite(DIS_DEC, LOW);
  delay(tiempo);

  digitalWrite(DIS_CEN, HIGH);
  delay(tiempo);
  lightSegments(centena);
  digitalWrite(DIS_CEN, LOW);
  delay(tiempo);

  digitalWrite(DIS_MIL, HIGH);
  delay(tiempo);
  lightSegments(mil);
  digitalWrite(DIS_MIL,LOW);
  delay(tiempo);
  
  unidad++;
}

/**
Esta funcion permite encender el segmento con el numero
pasando como argumento

int number del 0 al 9
*/
void lightSegments(int number) {
  byte numberBit = numbersDisplayAnode[number];

  //Recorremos dentro de los 7 pines
  for(int i=0 ; i<7 ; i++){
    int bit = bitRead(numberBit, i); //Obtenemos ese bite a int
    digitalWrite(pins[i], bit);      //Enciamos
  }  
}

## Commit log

2022-08-30 Usando la matriz de led
2022-08-30 Mostrando en las matris de led la temperatura y humedad
2022-08-30 Mostando en la matriz de leds la hora y fecha
2022-08-30 Modulo de sensor de hora y fecha
2022-08-30 Mostrar la hora con el multiplexado
2022-08-30 Montando en nuestro PCB
2022-08-30 Codigo Sensor Temepratura y humedad
